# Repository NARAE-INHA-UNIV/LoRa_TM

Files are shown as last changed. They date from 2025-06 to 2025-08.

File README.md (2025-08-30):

# LoRa TM

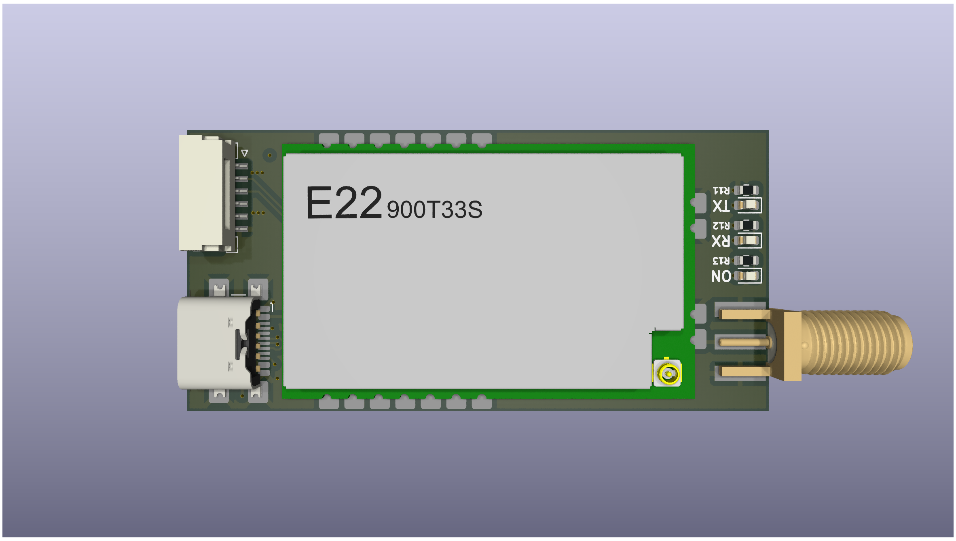
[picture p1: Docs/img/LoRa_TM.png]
LoRa TM

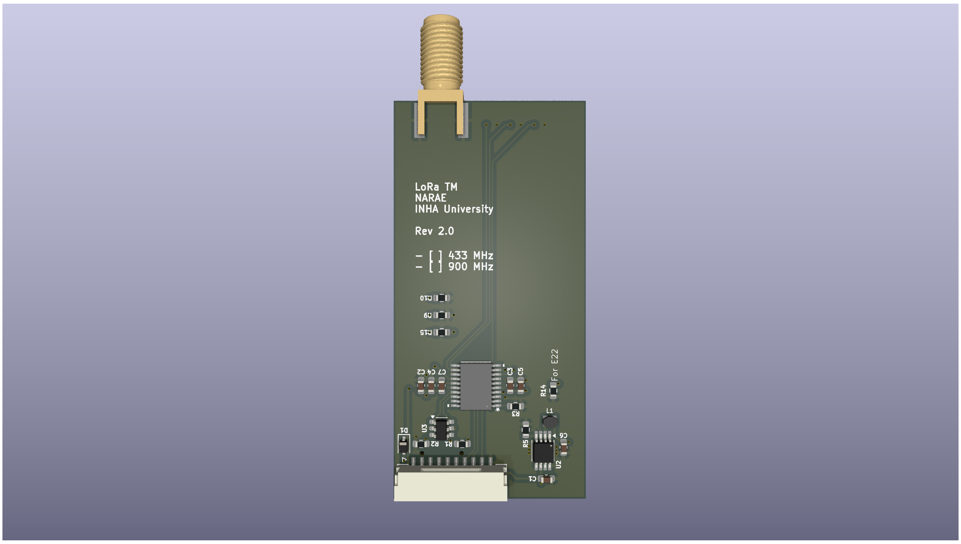
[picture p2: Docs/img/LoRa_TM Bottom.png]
LoRa TM BOTTOM


DIY telemetry module based Ebyte LoRa.

- 활동명 : [UAV] DIY Telemerty Module
- 일시 : 2024 동계방학
- 팀명 : 항공전자 (구 FC)
- 팀장 : 
  - 송민우 (2024) : 개념 설계, 회로 설계
  - 이현제 (2025) : 회로 설계, 펌웨어 작성

## USB CDC

ST에서 제공하는 라이브러리 사용시 RAM, Flash memory 용량 초과.

[Making USB Device With STM32 + TinyUSB](https://ejaaskel.dev/making-usb-device-with-stm32-tinyusb/)

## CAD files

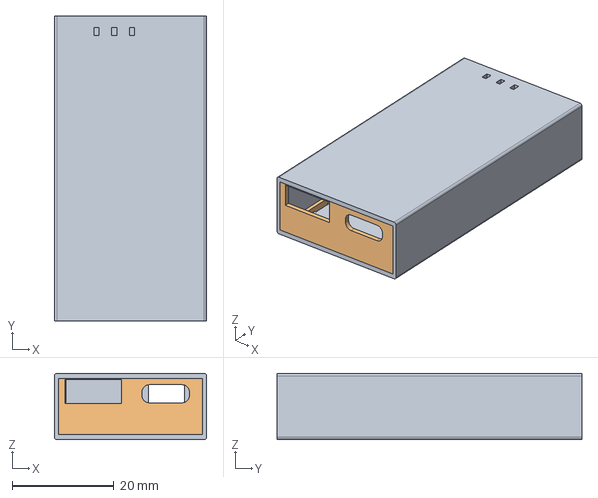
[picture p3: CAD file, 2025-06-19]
LoRa_TM Case.step
30.0 x 60.0 x 13.0 mm
Case
Case Top

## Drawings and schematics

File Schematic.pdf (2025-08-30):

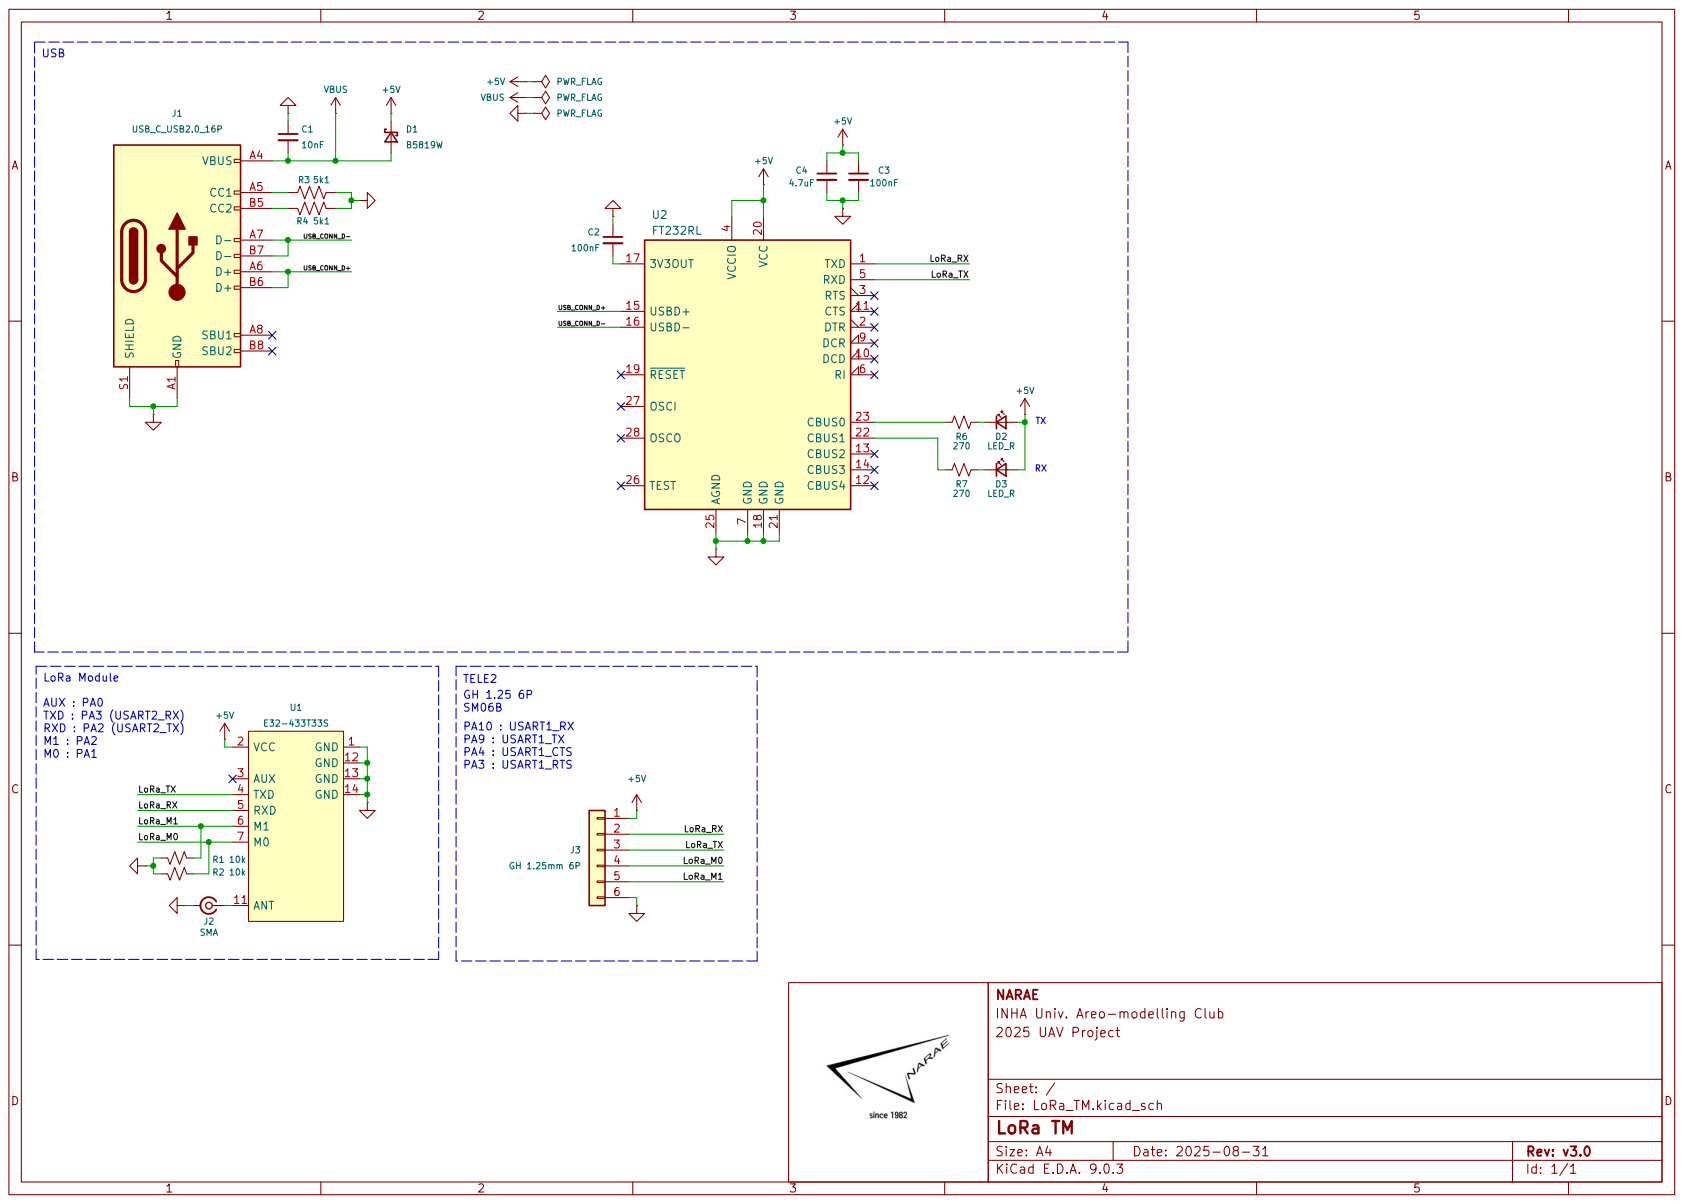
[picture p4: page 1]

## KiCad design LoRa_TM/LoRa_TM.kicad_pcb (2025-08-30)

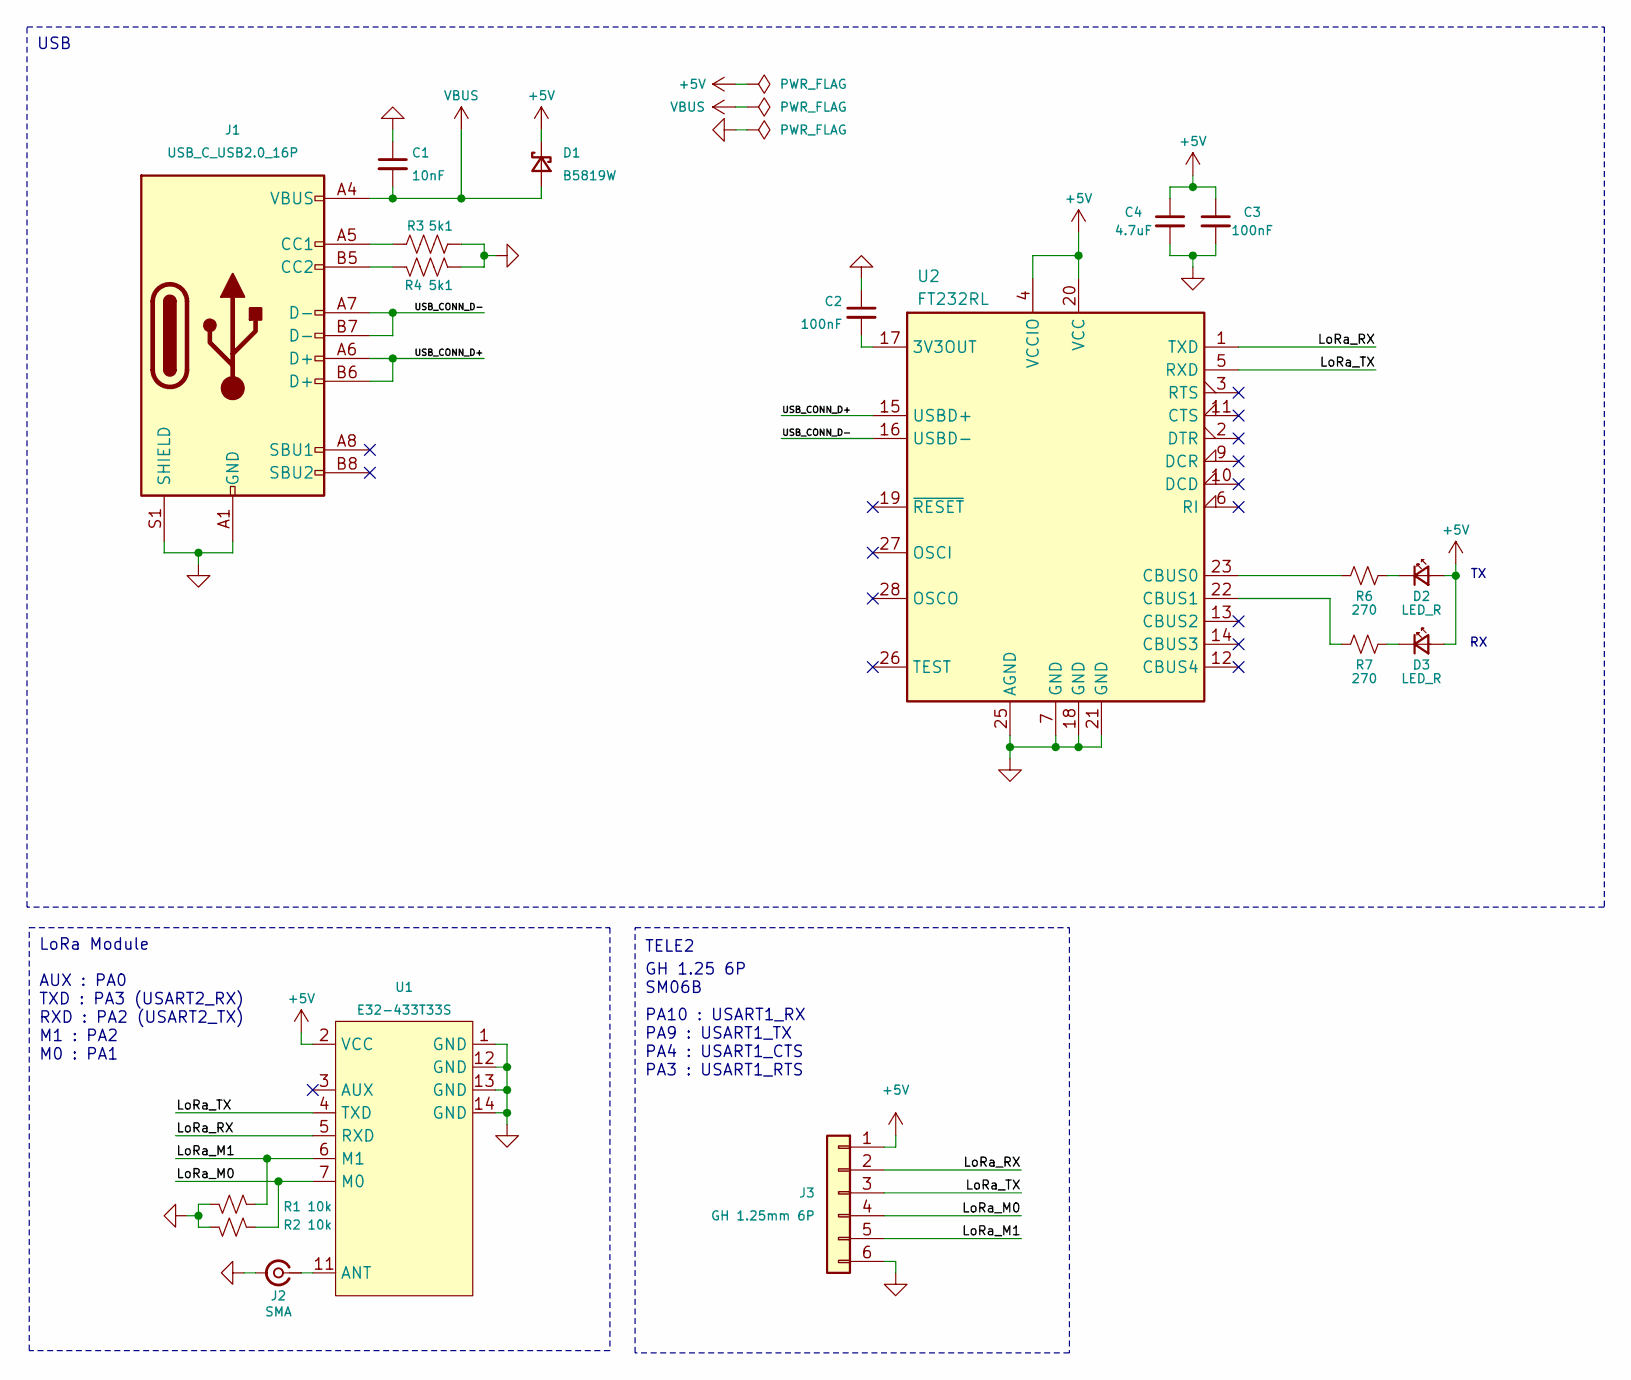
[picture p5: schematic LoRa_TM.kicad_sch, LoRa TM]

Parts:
C1: 10nF; C_0603_1608Metric; LCSC C1589
C2, C3: 100nF; C_0603_1608Metric; LCSC C1590
C4: 4.7uF; C_0603_1608Metric; LCSC C1705
D1: B5819W; D_SOD-323; LCSC C64885
D2, D3: LED_R; LED_0603_1608Metric; LCSC C2286
J1: USB_C_USB2.0_16P; USB_C_Receptacle_GCT_USB4105-xx-A_16P_TopMnt_Horizontal; LCSC C2765186
J2: SMA; SMA_EdgeMount; LCSC C376663
J3: GH 1.25mm 6P; JST_GH_SM06B-GHS-TB_06x1.25mm_Angled; LCSC C133065
R1, R2: 10k; R_0603_1608Metric; LCSC C15401
R3, R4: 5k1; R_0603_1608Metric; LCSC C14677
R6, R7: 270; R_0603_1608Metric; LCSC C22966
U1: E32-433T33S; E22-XXXT33S
U2: FT232RL; SSOP-28_5.3x10.2mm_P0.65mm; LCSC C8690

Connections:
+5V: C3.1, C4.1, D1.1 (K), D2.2 (A), D3.2 (A), J3.1, U1.2 (VCC), U2.4 (VCCIO), U2.20 (VCC)
/LoRa_M0: J3.4, R2.1, U1.7 (M0)
/LoRa_M1: J3.5, R1.1, U1.6 (M1)
/LoRa_RX: J3.2, U1.5 (RXD), U2.1 (TXD)
/LoRa_TX: J3.3, U1.4 (TXD), U2.5 (RXD)
/USB_CONN_D+: J1.A6 (D+), J1.B6 (D+), U2.15 (USBD+)
/USB_CONN_D-: J1.A7 (D-), J1.B7 (D-), U2.16 (USBD-)
GND: C1.1, C2.1, C3.2, C4.2, J1.A1 (GND), J1.A12 (GND), J1.B1 (GND), J1.B12 (GND), J1.S1 (SHIELD), J2.2 (Ext), J3.6, R1.2, R2.2, R3.2, R4.2, U1.1 (GND), U1.12 (GND), U1.13 (GND), U1.14 (GND), U2.7 (GND), U2.18 (GND), U2.21 (GND), U2.25 (AGND)
unnamed: D2.1 (K), R6.1
unnamed: D3.1 (K), R7.1
unnamed: J1.A5 (CC1), R3.1
unnamed: J1.B5 (CC2), R4.1
unnamed: J2.1 (In), U1.11 (ANT)
unnamed: C2.2, U2.17 (3V3OUT)
unnamed: R6.2, U2.23 (CBUS0)
unnamed: R7.2, U2.22 (CBUS1)
VBUS: C1.2, D1.2 (A), J1.A4 (VBUS), J1.A9 (VBUS), J1.B4 (VBUS), J1.B9 (VBUS)

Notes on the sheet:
TELE2
AUX : PA0 TXD : PA3 (USART2_RX) RXD : PA2 (USART2_TX) M1 : PA2 M0 : PA1
GH 1.25 6P SM06B
USB
PA10 : USART1_RX PA9 : USART1_TX PA4 : USART1_CTS PA3 : USART1_RTS
LoRa Module

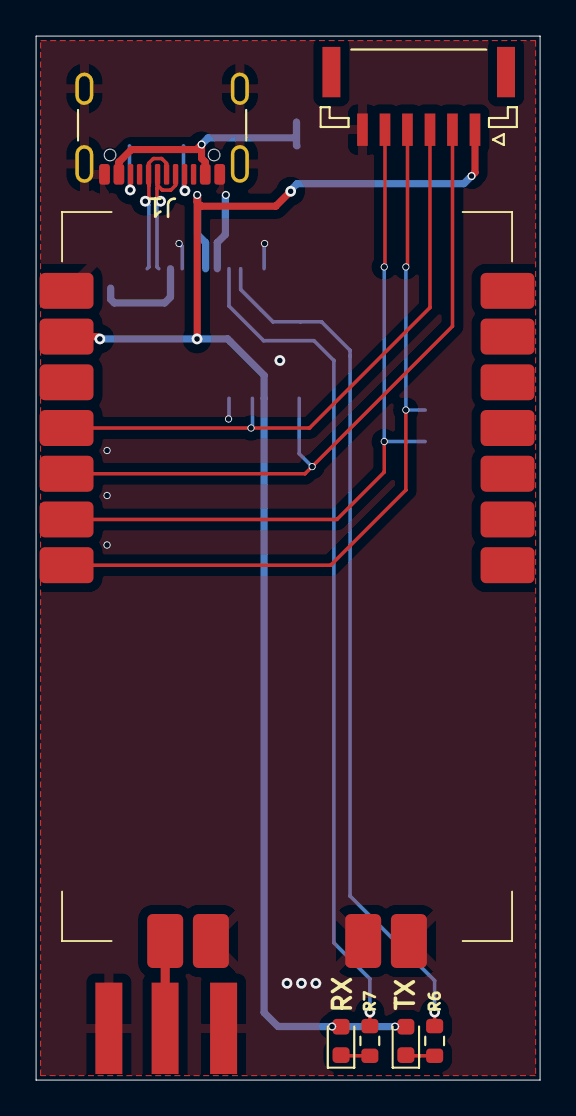
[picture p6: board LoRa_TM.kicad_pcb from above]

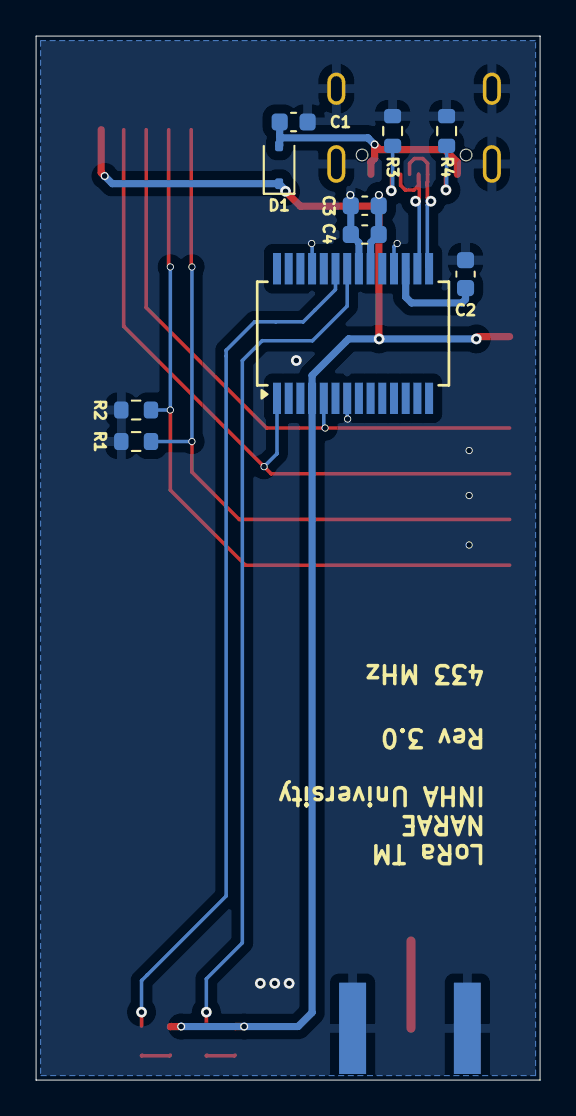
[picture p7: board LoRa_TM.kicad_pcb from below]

Board: 2 copper layers, 28.0 x 58.0 mm, 18 parts (10 on the bottom side), 17 nets.

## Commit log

2025-06-13 Schematic Done
    [LoRa_TM.kicad_pcb, LoRa_TM.kicad_sch]
2025-06-18 stm32u375 update
    [LoRa_TM.kicad_sch]
2025-06-18 PCB Done
    [LoRa_TM-B_Cu.gbr, LoRa_TM-B_Mask.gbr, LoRa_TM-B_Paste.gbr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]
2025-06-18 Schematic update
    [LoRa_TM.kicad_sch]
2025-06-19 minor fix
    [LoRa_TM Case.step, LoRa_TM.kicad_pcb]
2025-08-30 version 3
    [LoRa_TM Case.step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]
